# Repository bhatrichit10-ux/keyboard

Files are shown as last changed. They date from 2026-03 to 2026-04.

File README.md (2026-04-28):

# keyboard
my own very little keyboard!

i think i need a new keyboard, so whynot make a new one. hehehe

Well, its my first ever keyboard after i made my micropad. (Using qmk for first time aswell)
## Features
- 60% keyboard - 60 keys
- made using qmk
- uses pi pico
- simple matrix design
- easy to recreate

## Schematics
Matrix: <br>
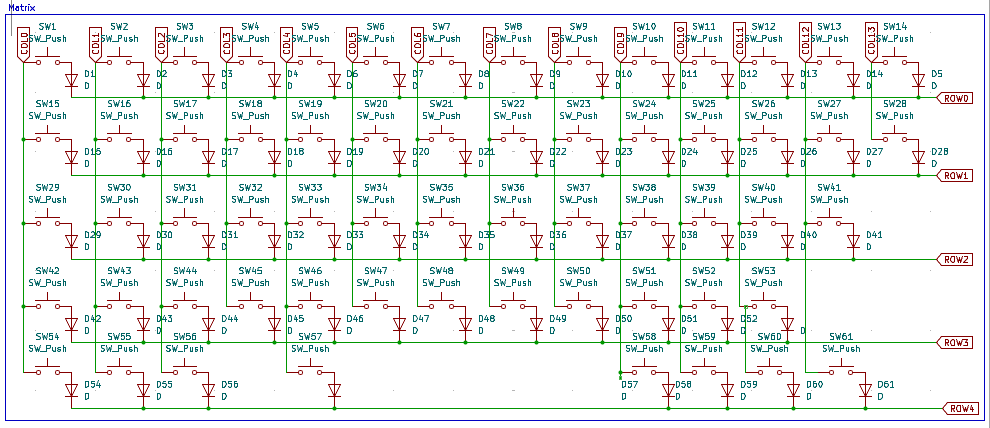
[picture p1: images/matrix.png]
Matrix
 <br>
Microcontroller: <br>
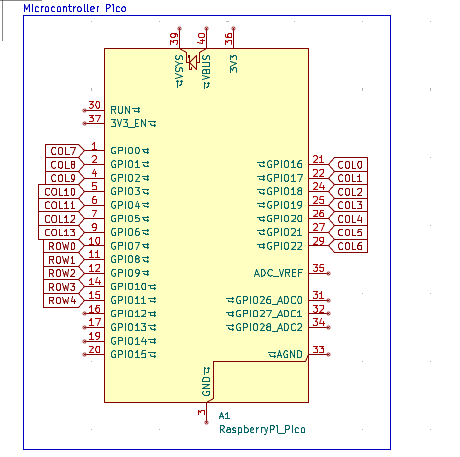
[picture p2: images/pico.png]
Pico
 <br>

## PCB Design
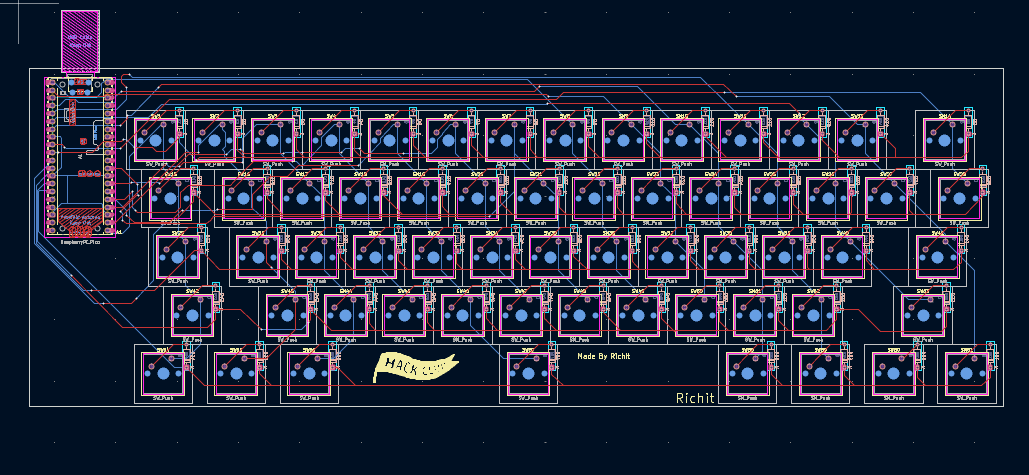
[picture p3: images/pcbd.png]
PCB Design

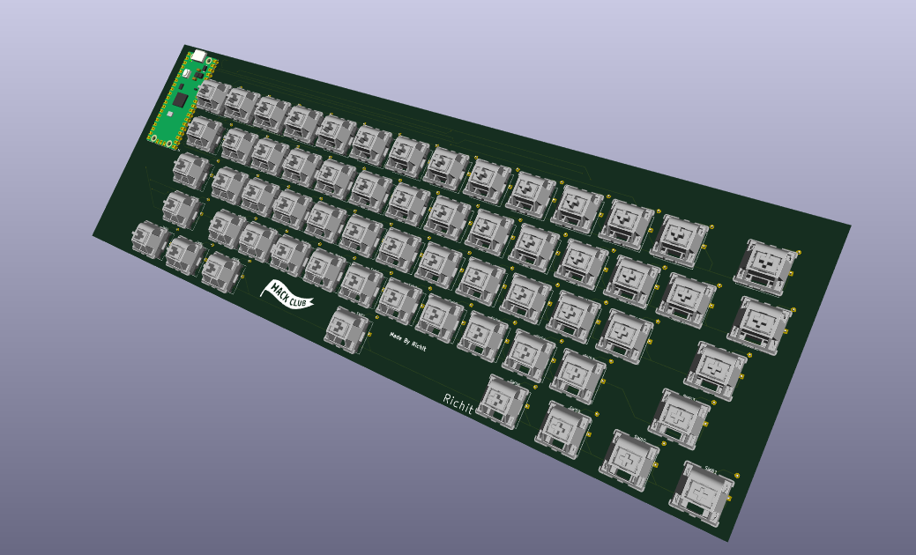
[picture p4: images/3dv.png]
3D Design

### PCB Checkout
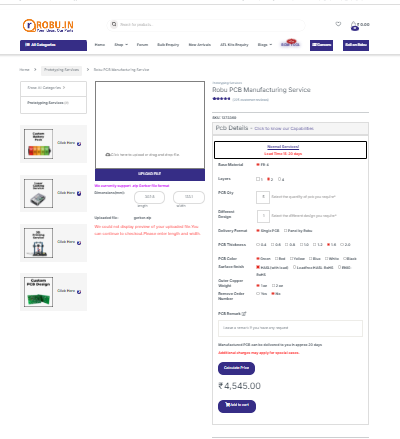
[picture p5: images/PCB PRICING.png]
<br>
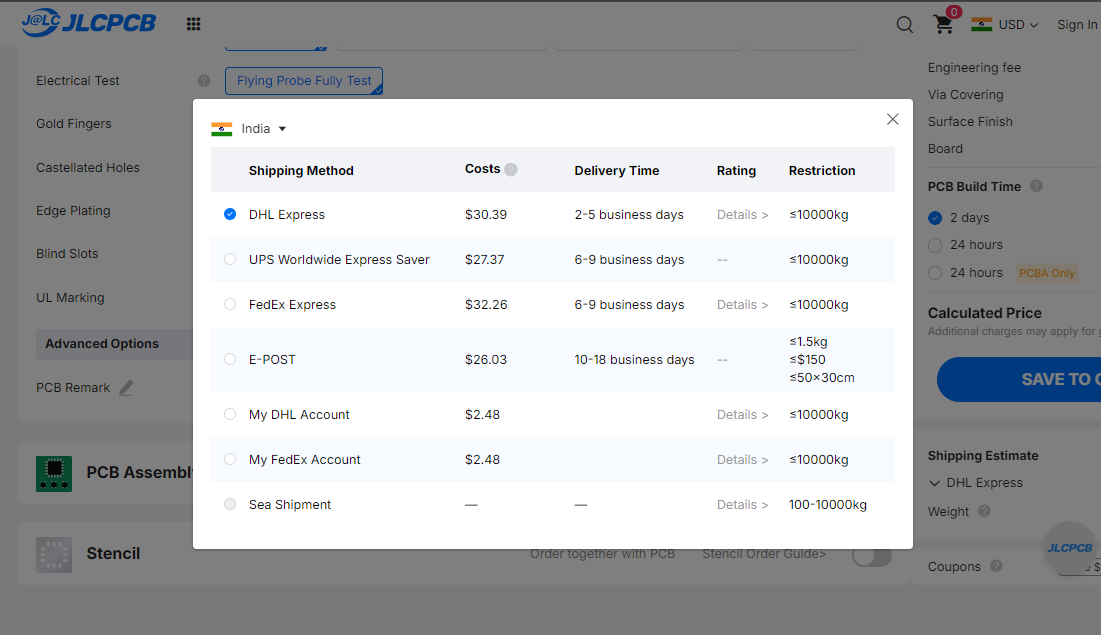
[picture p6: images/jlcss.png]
<br>
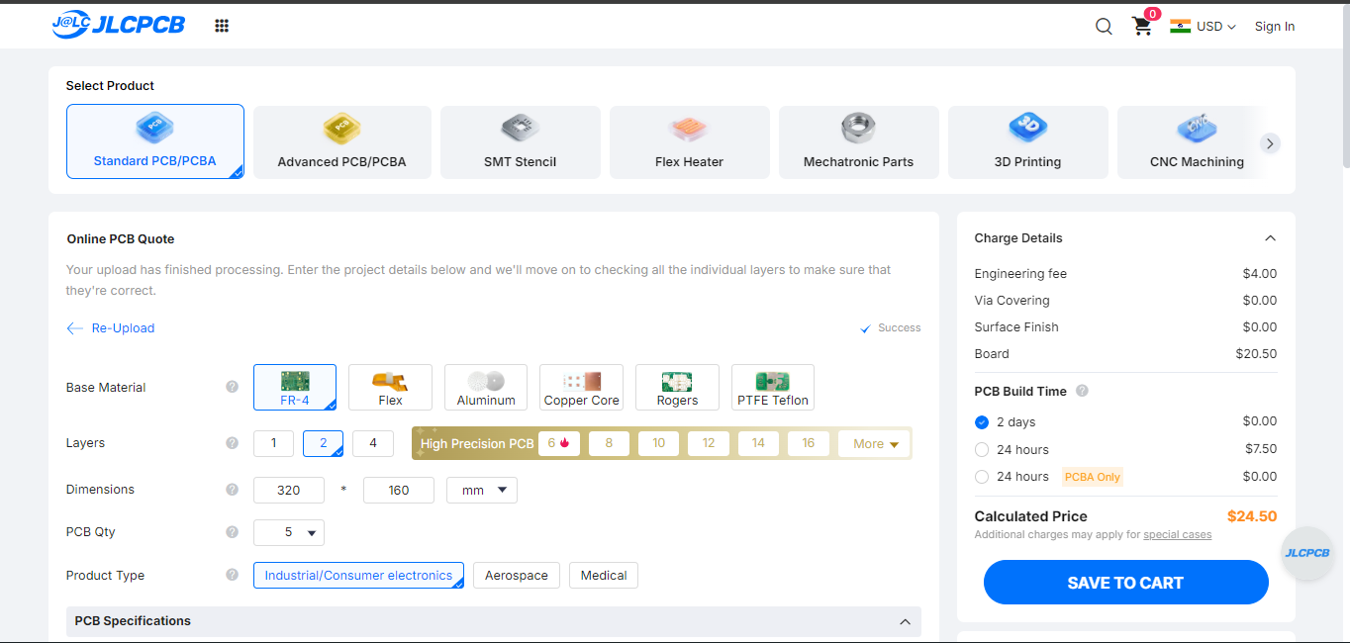
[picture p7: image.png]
somestuff


```
Q: Why did i use Robu instead of JLCPCB or SEEED STUDIO FUSION?
A: I live in India and, Robu might be expensive at first but actually it is alot cheaper! Shipping costs to me from JLCPCB and SEEEDSTUDIO FUSION are around $15-$30. Whereas at a little expensive cost, i can get from Robu which is India based and avoid customs as well!

Also my home is like in a region where its harder to ship stuff so maybe robu might also charge extra
```

## CAD 
Case with PCB: <br>
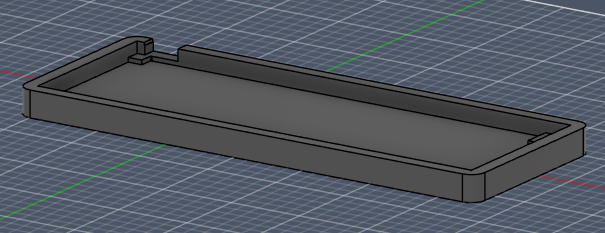
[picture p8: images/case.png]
PCB CASE
 <br>
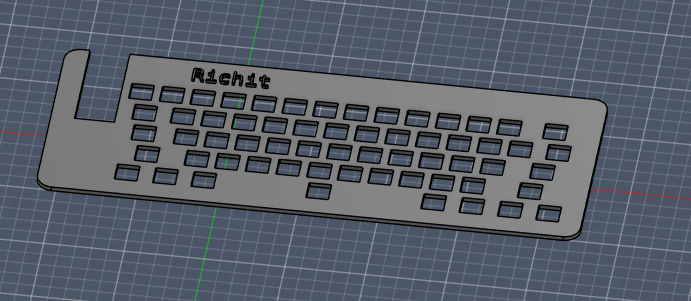
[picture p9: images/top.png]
 <br>
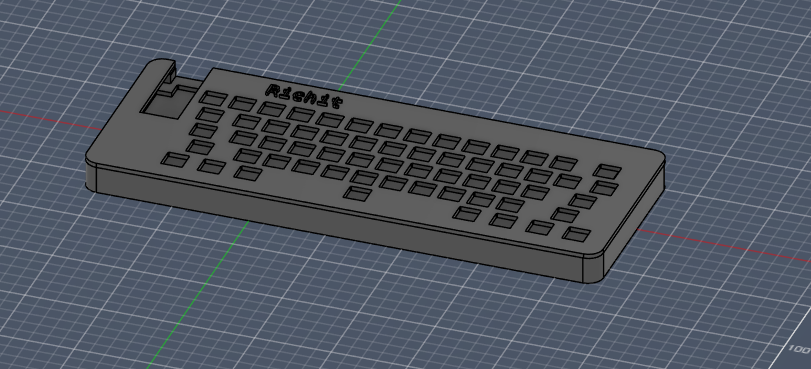
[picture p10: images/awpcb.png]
 <br>
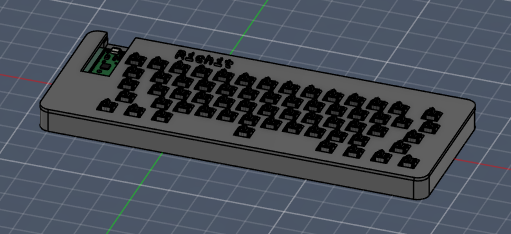
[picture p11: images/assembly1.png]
 <br>

## Firmware
I made the firmware using QMK. And compiled it in `firmware` directory

# BOM

|Name |Purpose |Quantity|Total Cost (USD)|Distributor |
|---|---|---|---|---|
|RPI Pico |The brain |1 |4.47 |RObu.in |
|Diodes ( Pack of 70) |Matrix Working  |7 |1.16 |Stacks KB |
|PCB |Connect stuff |1 |50.50 |Robu.in |
|Counter Strike Printstream Decal Collection Cherry PBT Keycaps|Keycaps |1 |18.07 |Curiosity Caps|
|Akko Botany Switch (Pack of 45) |Main Keyswicthes|2 |23.38 |Stacks KB |

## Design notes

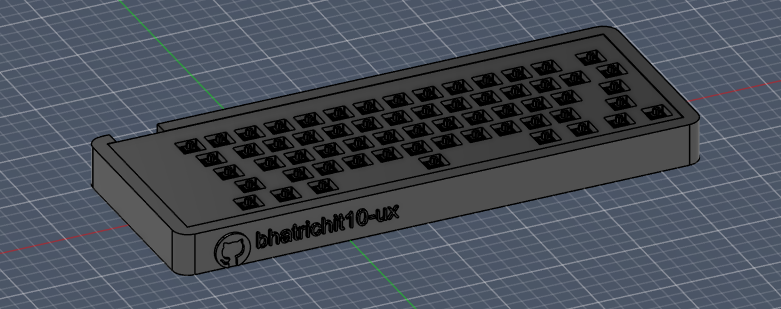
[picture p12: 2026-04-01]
images/a2top.png

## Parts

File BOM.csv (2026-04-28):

Name | Purpose | Quantity | Total Cost (USD) | Link | Distributor
RPI Pico | The brain | 1 | 4.47 | https://robu.in/product/raspberry-pi-pico | RObu.in
Diodes ( Pack of 70) | Matrix Working | 7 | 1.16 | https://stackskb.com/store/1n4148-through-hole-diode/ | Stacks KB
PCB | Connect stuff | 1 | 50.50 |  | Robu.in
Counter Strike Printstream Decal Collection Cherry PBT Keycaps | Keycaps | 1 | 18.07 | https://curiositycaps.in/products/counter-strike-printstream-decal-collectio-n-cherry-pbt-keycaps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 | Curiosity Caps
Akko Botany Switch (Pack of 45) | Main Keyswicthes | 2 | 23.38 | https://stackskb.com/store/akko-botany-switch-pack-of-45/ | Stacks KB

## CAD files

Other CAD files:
CAD/ASSEMBLY.step
CAD/Top.step
CAD/Case.step
CAD/Case_KB.stl
CAD/KBPCB.step

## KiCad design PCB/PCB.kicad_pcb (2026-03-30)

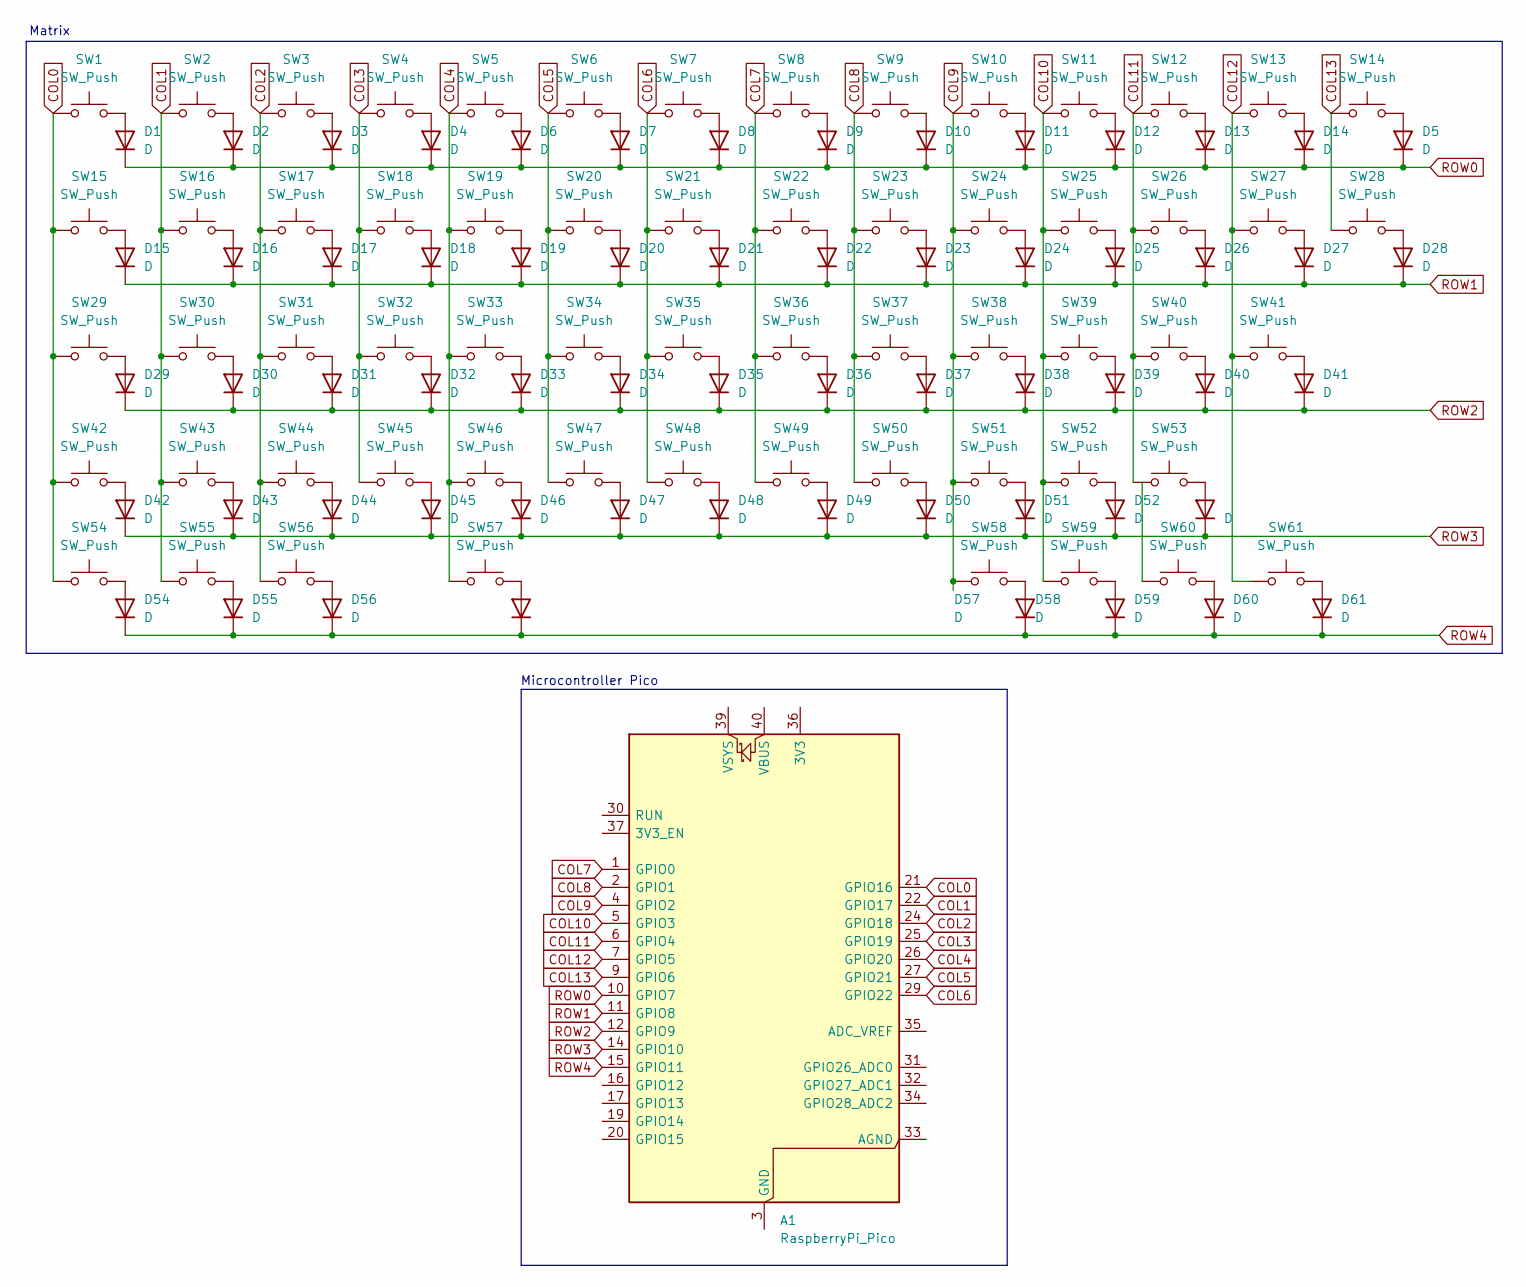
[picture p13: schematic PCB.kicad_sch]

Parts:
A1: RaspberryPi_Pico; RaspberryPi_Pico_Common_Unspecified
D1, D2, D3, D4, D5, D6, D7, D8, D9, D10, D11, D12, D13, D14, D15, D16, D17, D18, D19, D20, D21, D22, D23, D24, D25, D26, D27, D28, D29, D30, D31, D32, D33, D34, D35, D36, D37, D38, D39, D40, D41, D42, D43, D44, D45, D46, D47, D48, D49, D50, D51, D52, D53, D54, D55, D56, D57, D58, D59, D60, D61: D; D_DO-35_SOD27_P7.62mm_Horizontal
SW1, SW2, SW3, SW4, SW5, SW6, SW7, SW8, SW9, SW10, SW11, SW12, SW13, SW14, SW15, SW16, SW17, SW18, SW19, SW20, SW21, SW22, SW23, SW24, SW25, SW26, SW27, SW28, SW29, SW30, SW31, SW32, SW33, SW34, SW35, SW36, SW37, SW38, SW39, SW40, SW41, SW42, SW43, SW44, SW45, SW46, SW47, SW48, SW49, SW50, SW51, SW52, SW53, SW54, SW55, SW56, SW57, SW58, SW59, SW60, SW61: SW_Push; SW_Cherry_MX_1.00u_PCB

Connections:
COL0: A1.21 (GPIO16), SW1.1, SW15.1, SW29.1, SW42.1, SW54.1
COL1: A1.22 (GPIO17), SW2.1, SW16.1, SW30.1, SW43.1, SW55.1
COL2: A1.24 (GPIO18), SW3.1, SW17.1, SW31.1, SW44.1, SW56.1
COL3: A1.25 (GPIO19), SW4.1, SW18.1, SW32.1, SW45.1
COL4: A1.26 (GPIO20), SW5.1, SW19.1, SW33.1, SW46.1, SW57.1
COL5: A1.27 (GPIO21), SW6.1, SW20.1, SW34.1, SW47.1
COL6: A1.29 (GPIO22), SW7.1, SW21.1, SW35.1, SW48.1
COL7: A1.1 (GPIO0), SW8.1, SW22.1, SW36.1, SW49.1
COL8: A1.2 (GPIO1), SW9.1, SW23.1, SW37.1, SW50.1
COL9: A1.4 (GPIO2), SW10.1, SW24.1, SW38.1, SW51.1, SW58.1
COL10: A1.5 (GPIO3), SW11.1, SW25.1, SW39.1, SW52.1, SW59.1
COL11: A1.6 (GPIO4), SW12.1, SW26.1, SW40.1, SW53.1
COL12: A1.7 (GPIO5), SW13.1, SW27.1, SW41.1, SW61.1
COL13: A1.9 (GPIO6), SW14.1, SW28.1
unnamed: A1.3 (GND), A1.8 (GND), A1.13 (GND), A1.18 (GND), A1.23 (GND), A1.28 (GND), A1.38 (GND)
unnamed: D1.2 (A), SW1.2
unnamed: D2.2 (A), SW2.2
unnamed: D3.2 (A), SW3.2
unnamed: D4.2 (A), SW4.2
unnamed: D5.2 (A), SW14.2
unnamed: D6.2 (A), SW5.2
unnamed: D7.2 (A), SW6.2
unnamed: D8.2 (A), SW7.2
unnamed: D9.2 (A), SW8.2
unnamed: D10.2 (A), SW9.2
unnamed: D11.2 (A), SW10.2
unnamed: D12.2 (A), SW11.2
unnamed: D13.2 (A), SW12.2
unnamed: D14.2 (A), SW13.2
unnamed: D15.2 (A), SW15.2
unnamed: D16.2 (A), SW16.2
unnamed: D17.2 (A), SW17.2
unnamed: D18.2 (A), SW18.2
unnamed: D19.2 (A), SW19.2
unnamed: D20.2 (A), SW20.2
unnamed: D21.2 (A), SW21.2
unnamed: D22.2 (A), SW22.2
unnamed: D23.2 (A), SW23.2
unnamed: D24.2 (A), SW24.2
unnamed: D25.2 (A), SW25.2
unnamed: D26.2 (A), SW26.2
unnamed: D27.2 (A), SW27.2
unnamed: D28.2 (A), SW28.2
unnamed: D29.2 (A), SW29.2
unnamed: D30.2 (A), SW30.2
unnamed: D31.2 (A), SW31.2
unnamed: D32.2 (A), SW32.2
unnamed: D33.2 (A), SW33.2
unnamed: D34.2 (A), SW34.2
unnamed: D35.2 (A), SW35.2
unnamed: D36.2 (A), SW36.2
unnamed: D37.2 (A), SW37.2
unnamed: D38.2 (A), SW38.2
unnamed: D39.2 (A), SW39.2
unnamed: D40.2 (A), SW40.2
unnamed: D41.2 (A), SW41.2
unnamed: D42.2 (A), SW42.2
unnamed: D43.2 (A), SW43.2
unnamed: D44.2 (A), SW44.2
unnamed: D45.2 (A), SW45.2
unnamed: D46.2 (A), SW46.2
unnamed: D47.2 (A), SW47.2
unnamed: D48.2 (A), SW48.2
unnamed: D49.2 (A), SW49.2
unnamed: D50.2 (A), SW50.2
unnamed: D51.2 (A), SW51.2
unnamed: D52.2 (A), SW52.2
unnamed: D53.2 (A), SW53.2
unnamed: D54.2 (A), SW54.2
unnamed: D55.2 (A), SW55.2
unnamed: D56.2 (A), SW56.2
unnamed: D57.2 (A), SW57.2
unnamed: D58.2 (A), SW58.2
unnamed: D59.2 (A), SW59.2
unnamed: D60.2 (A), SW60.1
unnamed: D61.2 (A), SW61.2
ROW0: A1.10 (GPIO7), D1.1 (K), D2.1 (K), D3.1 (K), D4.1 (K), D5.1 (K), D6.1 (K), D7.1 (K), D8.1 (K), D9.1 (K), D10.1 (K), D11.1 (K), D12.1 (K), D13.1 (K), D14.1 (K)
ROW1: A1.11 (GPIO8), D15.1 (K), D16.1 (K), D17.1 (K), D18.1 (K), D19.1 (K), D20.1 (K), D21.1 (K), D22.1 (K), D23.1 (K), D24.1 (K), D25.1 (K), D26.1 (K), D27.1 (K), D28.1 (K)
ROW2: A1.12 (GPIO9), D29.1 (K), D30.1 (K), D31.1 (K), D32.1 (K), D33.1 (K), D34.1 (K), D35.1 (K), D36.1 (K), D37.1 (K), D38.1 (K), D39.1 (K), D40.1 (K), D41.1 (K)
ROW3: A1.14 (GPIO10), D42.1 (K), D43.1 (K), D44.1 (K), D45.1 (K), D46.1 (K), D47.1 (K), D48.1 (K), D49.1 (K), D50.1 (K), D51.1 (K), D52.1 (K), D53.1 (K)
ROW4: A1.15 (GPIO11), D54.1 (K), D55.1 (K), D56.1 (K), D57.1 (K), D58.1 (K), D59.1 (K), D60.1 (K), D61.1 (K)

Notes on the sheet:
Matrix
Microcontroller Pico

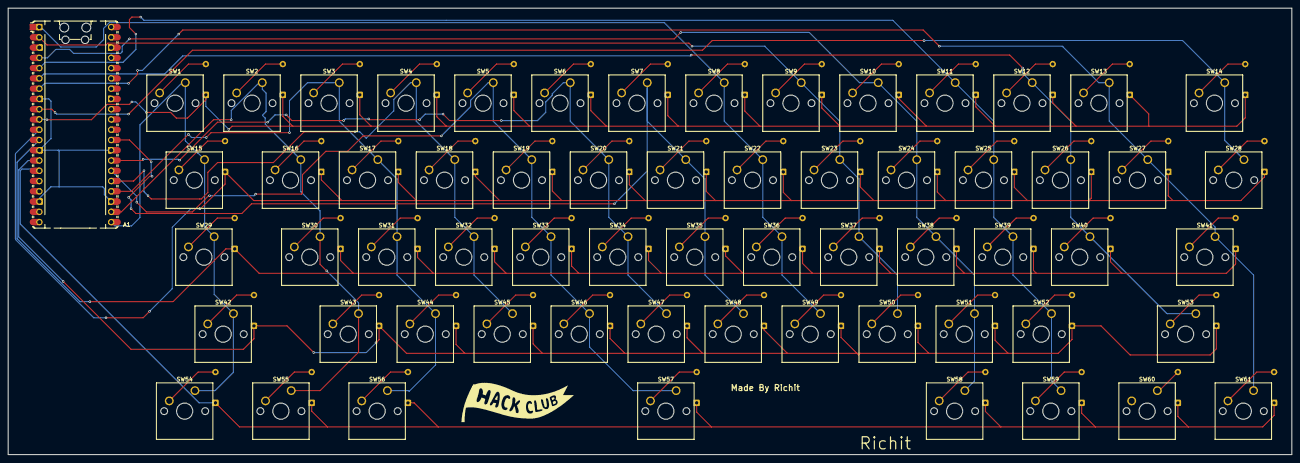
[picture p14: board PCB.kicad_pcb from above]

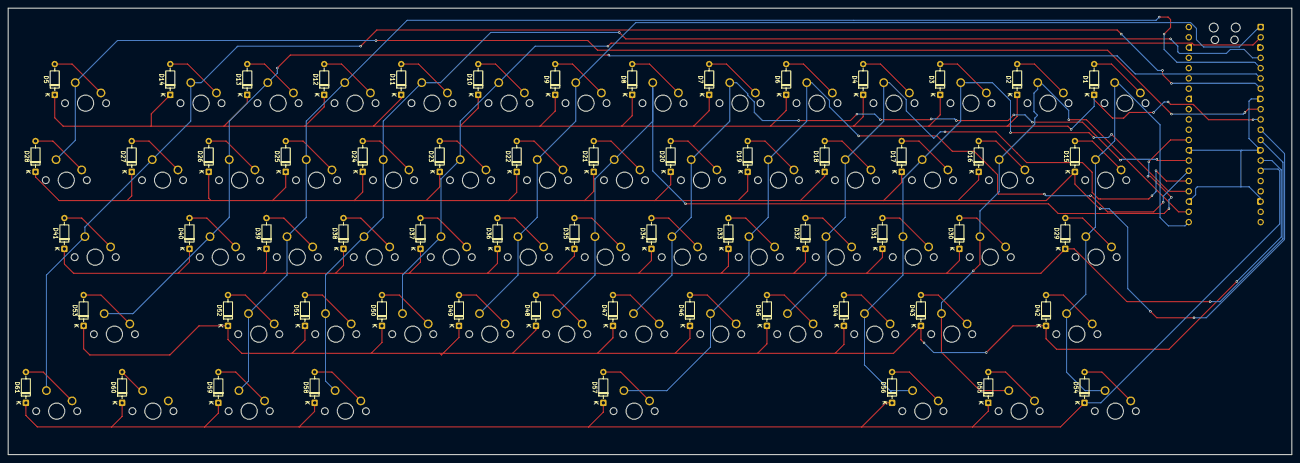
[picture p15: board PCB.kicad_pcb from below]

Board: 2 copper layers, 317.6 x 110.4 mm, 123 parts (61 on the bottom side), 81 nets.

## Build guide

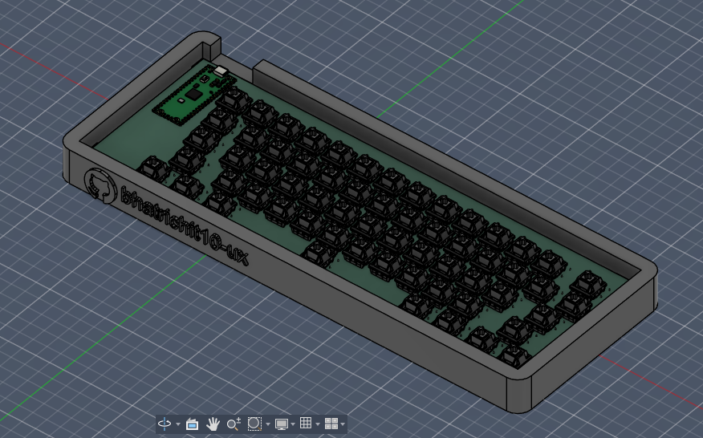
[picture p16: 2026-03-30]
images/assembly.png

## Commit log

2026-03-13 Made schematics
    [PCB.kicad_pcb, PCB.kicad_sch]
2026-03-14 Added PCB
    [BOM.csv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]
2026-03-16 Mar 16, 2026, 4:56 PM
    [BOM.csv, Case With PCB.step, Case.step]
2026-03-16 Update BOM.csv with new diode pricing and links
    [BOM.csv]
2026-03-16 Update BOM.csv with note clarification
    [BOM.csv]
2026-03-22 Ready to SHip!
    [Case With PCB.step, Case.step, Case_KB.stl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]
2026-03-25 With Gerber
    [PCB-B_Cu.gbr, PCB-B_Mask.gbr, PCB-B_Paste.gbr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]
2026-03-30 Ship time maybe
    [BOM.csv, Case_KB.stl, Case_KB_ASSEMBLY.stl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]
2026-03-31 USE LFS ON STEP/STL
2026-03-31 USE LFS ON STEP/STL again
2026-03-31 Remove obsolete files related to PCB design and logging
    - Deleted gerber.zip as it is no longer needed.
    - Removed kbplacer.log which contained outdated plugin information.
    - Cleared lock files (~PCB.kicad_sch.lck and ~_autosave-PCB.kicad_pcb.lck) to prevent conflicts.
    [PCB-B_Cu.gbr, PCB-B_Mask.gbr, PCB-B_Paste.gbr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]
2026-04-01 stuff: rts
    [ASSEMBLY.step, Case_KB_ASSEMBLY.stl]
2026-04-25 Ready to Ship #3
    [ASSEMBLY.step, Case.step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]
2026-04-26 fixed lfs
    [BOM.csv, Keyboard-bom.csv]
2026-04-28 Ready to ship finaly
    [BOM.csv]
